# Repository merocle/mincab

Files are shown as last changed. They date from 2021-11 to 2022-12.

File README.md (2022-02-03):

# MinCab. Small carrier board for Raspberry Pi CM4

[Official website uplab.pro](https://uplab.pro/ls/)

[More information about MinCab project](https://uplab.pro/2021/10/mincab/)

[MinCab v2 real preview](https://twitter.com/Merocle/status/1486014687162552329) (fixed version in the repository)

Article on [tomshardware.com (link)](https://www.tomshardware.com/news/raspberry-pi-compute-module-4-mincab)

Article on [hackster.io (link)](https://www.hackster.io/news/ivan-kuleshov-s-mincab-is-the-smallest-functional-raspberry-pi-compute-module-4-carrier-board-yet-b1cacfa2abad)

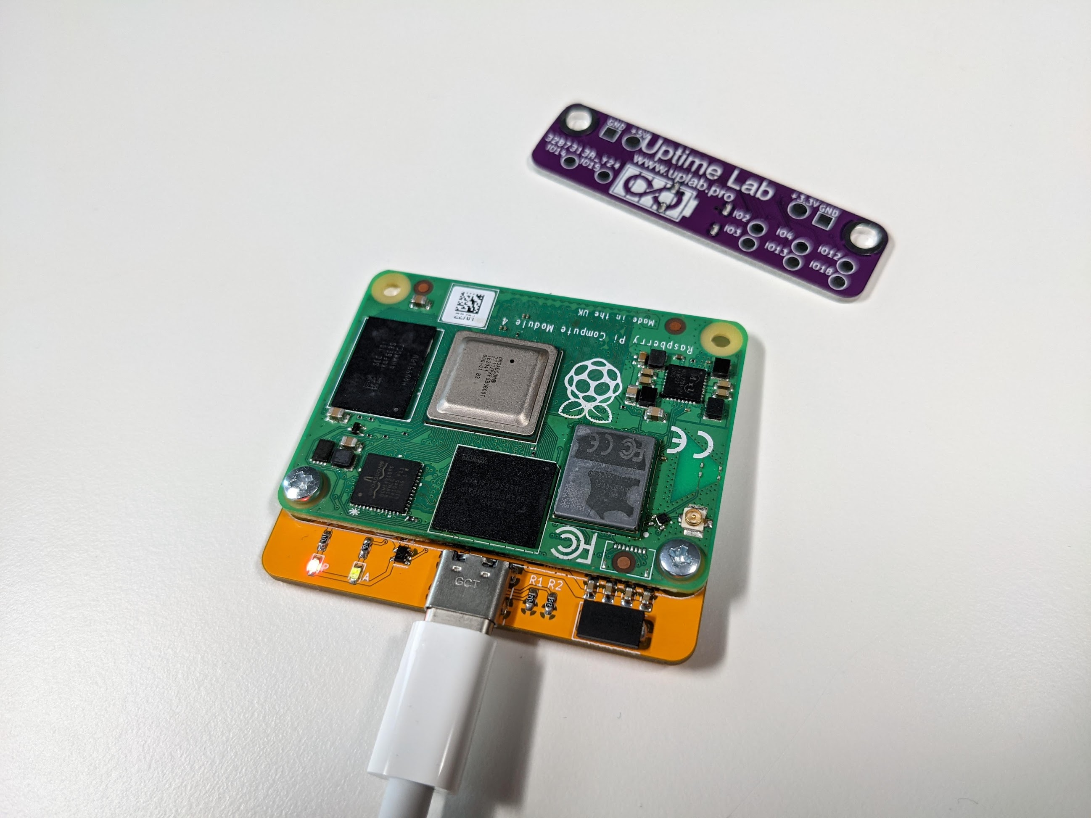
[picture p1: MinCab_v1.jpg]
Uptime MinCab carrier board for Raspberry Pi CM4

</br>
 <a rel="license" href="https://creativecommons.org/licenses/by-sa/4.0/">Creative Commons Attribution-ShareAlike 4.0 International License</a>.

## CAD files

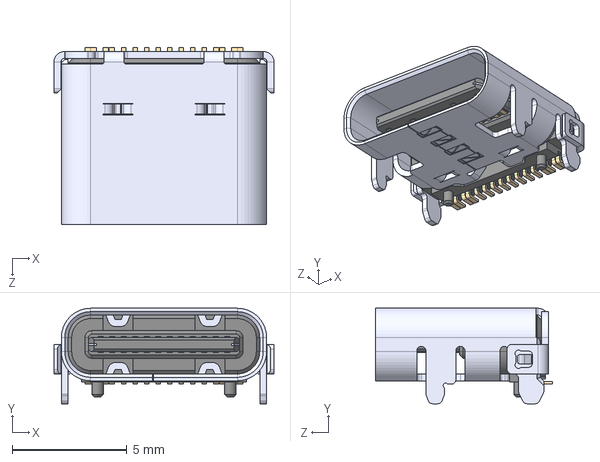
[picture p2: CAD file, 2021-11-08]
MinCab_v3.0/Kicad project/parts/USB4105-GF-A/USB4105-GF-A.step
9.58 x 4.16 x 7.71 mm

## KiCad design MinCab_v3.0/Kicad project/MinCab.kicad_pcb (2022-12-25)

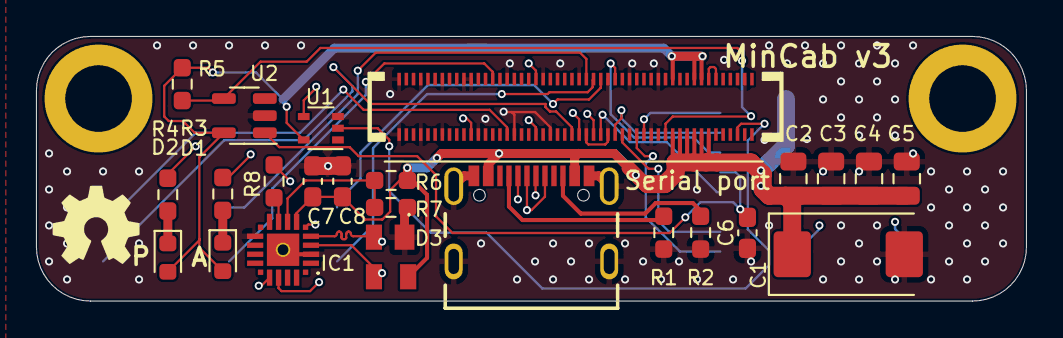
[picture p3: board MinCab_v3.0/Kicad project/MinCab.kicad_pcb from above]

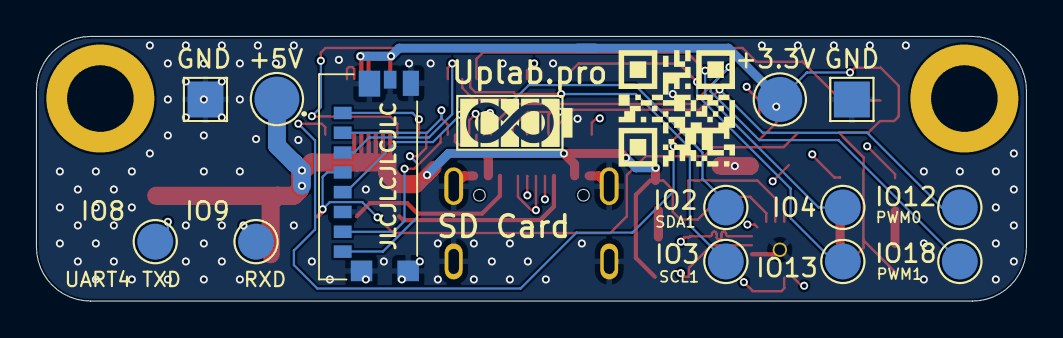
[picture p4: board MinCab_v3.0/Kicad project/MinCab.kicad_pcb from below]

Board: 4 copper layers, 55.0 x 14.7 mm, 37 parts (13 on the bottom side), 34 nets.

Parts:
+3.3V1: +3.3V; TestPoint_Pad_D2.5mm
+5V1: +5V; TestPoint_Pad_D2.5mm
C1: 100uF; CP_EIA-7343-31_Kemet-D
C2, C3, C4, C5: 10u; C_0805_2012Metric
C6: 10u; C_0603_1608Metric_Pad1.08x0.95mm_HandSolder
C7: 4.7uF; C_0603_1608Metric_Pad1.08x0.95mm_HandSolder
C8: 100nF; C_0603_1608Metric_Pad1.08x0.95mm_HandSolder
D1: LED Blue; LED_0603_1608Metric
D2: LED White; LED_0603_1608Metric
D3: SP0503BAHTG
GND1, GND2: GND; TestPoint_Pad_2.0x2.0mm
IC1: CP2102N-A02-GQFN20; CP2102NA02GQFN20
IO1: GPIO2; TestPoint_Pad_D2.0mm
IO2: GPIO12; TestPoint_Pad_D2.0mm
IO3: GPIO13; TestPoint_Pad_D2.0mm
IO4: GPIO3; TestPoint_Pad_D2.0mm
IO5: GPIO14; TestPoint_Pad_D2.0mm
IO6: GPIO4; TestPoint_Pad_D2.0mm
IO7: GPIO8; TestPoint_Pad_D2.0mm
IO8: GPIO9; TestPoint_Pad_D2.0mm
J1: USB4105-GF-A; GCT_USB4105-GF-A
J2: 47571-0001; 475710001
Module1: ComputeModule4; Raspberry-Pi-4-Compute-Module-big-holes
R1, R2: 5.1k; R_0603_1608Metric_Pad0.98x0.95mm_HandSolder
R3, R4: 1k; R_0603_1608Metric_Pad0.98x0.95mm_HandSolder
R5: 12K 1%; R_0603_1608Metric_Pad0.98x0.95mm_HandSolder
R6: 22K; R_0603_1608Metric_Pad0.98x0.95mm_HandSolder
R7: 47K; R_0603_1608Metric_Pad0.98x0.95mm_HandSolder
R8: 1K; R_0603_1608Metric_Pad0.98x0.95mm_HandSolder
U1: 74LVC1G07SE-7; SOT-353_SC-70-5
U2: RT9742GGJ5; SOT-23-5

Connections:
/+3.3v: +3.3V1.1, D1.2 (A), D2.2 (A), Module1.78 (GPIO_VREF(1.8v/3.3v_Input)), Module1.84 (+3.3v_(Output)), Module1.86 (+3.3v_(Output)), R5.1, U1.5 (VCC), U2.5 (IN)
/+5v: +5V1.1, C1.1, C2.1, C3.1, C4.1, C5.1, C7.2, C8.2, D3.4 (K_3), IC1.7 (VREGIN), J1.A4_B9 (VBUS), J1.B4_A9 (VBUS), Module1.77 (+5v_(Input)), Module1.79 (+5v_(Input)), Module1.81 (+5v_(Input)), Module1.83 (+5v_(Input)), Module1.85 (+5v_(Input)), Module1.87 (+5v_(Input)), R6.2
/D+: D3.3 (K_2), IC1.4 (D+), J1.A6 (DP1), J1.B6 (DP2)
/D-: D3.2 (K_1), IC1.5 (D-), J1.A7 (DN1), J1.B7 (DN2)
/GPIO2: IO1.1, Module1.58 (GPIO2)
/GPIO3: IO4.1, Module1.56 (GPIO3)
/GPIO4: IO6.1, Module1.54 (GPIO4)
/GPIO8: IO5.1, Module1.39 (GPIO8)
/GPIO9: IO7.1, Module1.40 (GPIO9)
/GPIO12: IO2.1, Module1.31 (GPIO12)
/GPIO13: IO3.1, Module1.28 (GPIO13)
/GPIO14: IC1.17 (RXD), Module1.55 (GPIO14)
/GPIO15: IC1.18 (TXD), Module1.51 (GPIO15)
/GPIO18: IO8.1, Module1.49 (GPIO18)
/SD_CLK: J2.P5 (CLK), Module1.57 (SD_CLK)
/SD_CMD: J2.P3 (CMD), Module1.62 (SD_CMD)
/SD_DAT0: J2.P7 (DAT0), Module1.63 (SD_DAT0)
/SD_DAT1: J2.P8 (DAT1), Module1.67 (SD_DAT1)
/SD_DAT2: J2.P1 (DAT2), Module1.69 (SD_DAT2)
/SD_DAT3: J2.P2 (CD/DAT3), Module1.61 (SD_DAT3)
/SD_PWR: C6.1, J2.P4 (VDD), U2.1 (OUT)
/SD_PWR_ON: Module1.75 (SD_PWR_ON), R5.2, U2.4 (EN)
/nPWR_LED: Module1.95 (nPI_LED_PWR), U1.2
GND: C1.2, C2.2, C3.2, C4.2, C5.2, C6.2, C7.1, C8.1, D3.1 (COMMON_A), GND1.1, GND2.1, IC1.3 (GND_1), IC1.12 (GND_2), IC1.21 (EP_GND), J1.A1_B12 (GND), J1.B1_A12 (GND), J1.S1 (SHELL_GND), J1.S2 (SHELL_GND), J1.S3 (SHELL_GND), J1.S4 (SHELL_GND), J2.G1 (GND_1), J2.G2 (GND_2), J2.G3 (GND_3), J2.G4 (POL), J2.G5 (DET), J2.P6 (VSS), Module1.1 (GND), Module1.2 (GND), Module1.7 (GND), Module1.8 (GND), Module1.13 (GND), Module1.14 (GND), Module1.20 (EEPROM_nWP), Module1.22 (GND), Module1.23 (GND), Module1.32 (GND), Module1.33 (GND), Module1.42 (GND), Module1.43 (GND), Module1.52 (GND), Module1.53 (GND), Module1.59 (GND), Module1.60 (GND), Module1.65 (GND), Module1.66 (GND), Module1.71 (GND), Module1.74 (GND), Module1.98 (GND), R1.2, R2.1, R7.1, U1.3 (GND), U2.2 (GND)
unnamed: D1.1 (K), R3.1
unnamed: D2.1 (K), R4.1
unnamed: IC1.6 (VDD), R8.1
unnamed: IC1.8 (VBUS), R6.1, R7.2
unnamed: IC1.9 (RSTB), R8.2
unnamed: J1.A5 (CC1), R1.1
unnamed: J1.B5 (CC2), R2.2
unnamed: Module1.21 (PI_nLED_Activity), R4.2
unnamed: Module1.88 (+1.8v_(Output)), Module1.90 (+1.8v_(Output))
unnamed: R3.2, U1.4

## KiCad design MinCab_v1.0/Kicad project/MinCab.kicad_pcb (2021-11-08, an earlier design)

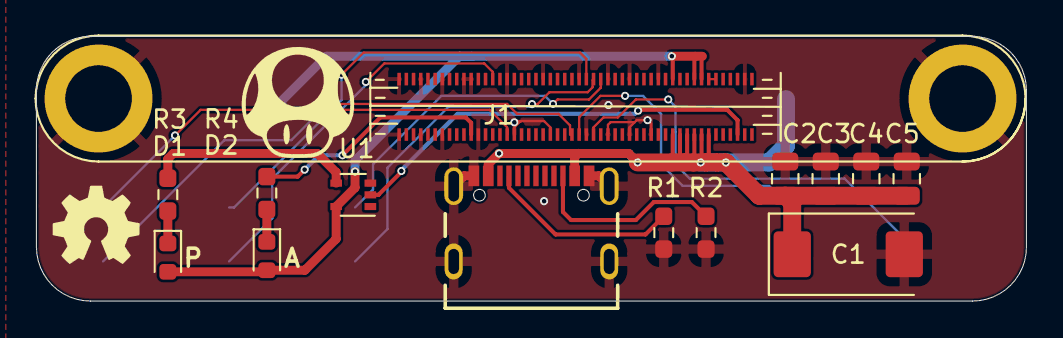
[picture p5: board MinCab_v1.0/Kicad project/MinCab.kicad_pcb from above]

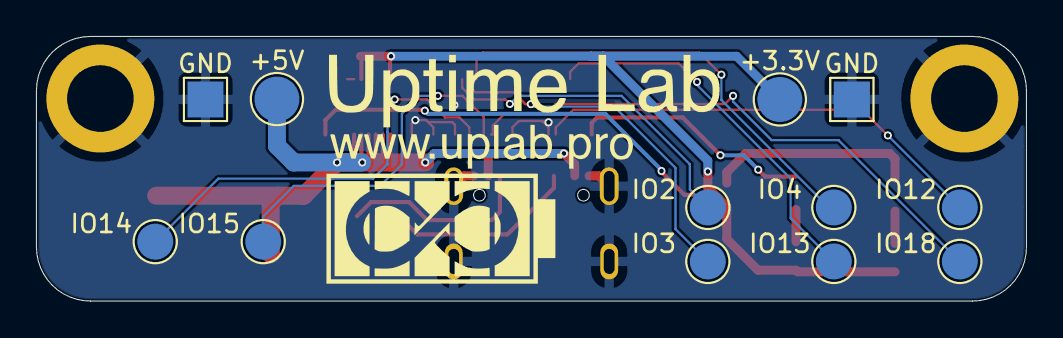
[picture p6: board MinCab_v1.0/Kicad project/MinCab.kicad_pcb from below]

Board: 2 copper layers, 55.0 x 14.7 mm, 26 parts (12 on the bottom side), 19 nets.

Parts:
+3.3V, +5V: TestPoint; TestPoint_Pad_D2.5mm
C1: 100uF; CP_EIA-7343-31_Kemet-D
C2, C3, C4, C5: 10u; C_0805_2012Metric
D1: LED Blue; LED_0603_1608Metric
D2: LED White; LED_0603_1608Metric
GND: TestPoint; TestPoint_Pad_2.0x2.0mm
GND#2: TestPoint; TestPoint_Pad_2.0x2.0mm
IO2, IO3, IO4, IO12, IO13, IO14, IO15, IO18: TestPoint; TestPoint_Pad_D2.0mm
J1: USB4105-GF-A; GCT_USB4105-GF-A
Module1: ComputeModule4; Raspberry-Pi-4-Compute-Module-big-holes
R1, R2: 5.1k; R_0603_1608Metric_Pad0.98x0.95mm_HandSolder
R3, R4: 1k; R_0603_1608Metric_Pad0.98x0.95mm_HandSolder
U1: 74LVC1G07SE-7; SOT-353_SC-70-5

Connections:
/+1.8v: Module1.88 (+1.8v_(Output)), Module1.90 (+1.8v_(Output))
/+3.3v: +3.3V.1, D1.2 (A), D2.2 (A), Module1.78 (GPIO_VREF(1.8v/3.3v_Input)), Module1.84 (+3.3v_(Output)), Module1.86 (+3.3v_(Output)), U1.5 (VCC)
/+5v: +5V.1, C1.1, C2.1, C3.1, C4.1, C5.1, J1.A4_B9 (VBUS), J1.B4_A9 (VBUS), Module1.77 (+5v_(Input)), Module1.79 (+5v_(Input)), Module1.81 (+5v_(Input)), Module1.83 (+5v_(Input)), Module1.85 (+5v_(Input)), Module1.87 (+5v_(Input))
/GPIO2: IO2.1, Module1.58 (GPIO2)
/GPIO3: IO3.1, Module1.56 (GPIO3)
/GPIO4: IO4.1, Module1.54 (GPIO4)
/GPIO12: IO12.1, Module1.31 (GPIO12)
/GPIO13: IO13.1, Module1.28 (GPIO13)
/GPIO14: IO14.1, Module1.55 (GPIO14)
/GPIO15: IO15.1, Module1.51 (GPIO15)
/GPIO18: IO18.1, Module1.49 (GPIO18)
/nPWR_LED: Module1.95 (nPI_LED_PWR), U1.2
GND: C1.2, C2.2, C3.2, C4.2, C5.2, GND.1, GND#2.1, J1.A1_B12 (GND), J1.B1_A12 (GND), J1.S1 (SHELL_GND), J1.S2 (SHELL_GND), J1.S3 (SHELL_GND), J1.S4 (SHELL_GND), Module1.1 (GND), Module1.2 (GND), Module1.7 (GND), Module1.8 (GND), Module1.13 (GND), Module1.14 (GND), Module1.20 (EEPROM_nWP), Module1.22 (GND), Module1.23 (GND), Module1.32 (GND), Module1.33 (GND), Module1.42 (GND), Module1.43 (GND), Module1.52 (GND), Module1.53 (GND), Module1.59 (GND), Module1.60 (GND), Module1.65 (GND), Module1.66 (GND), Module1.71 (GND), Module1.74 (GND), Module1.98 (GND), Module1.S2, R1.1, R2.2, U1.3 (GND)
unnamed: D1.1 (K), R3.1
unnamed: D2.1 (K), R4.1
unnamed: J1.A5 (CC1), R1.2
unnamed: J1.B5 (CC2), R2.1
unnamed: Module1.21 (PI_nLED_Activity), R4.2
unnamed: R3.2, U1.4

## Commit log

2021-11-08 Leeroy Jenkins
    no, just initial commit
    [MinCab-B_Cu.gbl, MinCab-B_Mask.gbs, MinCab-B_Paste.gbp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]
2021-12-01 added gerber files without mushroom
2022-02-03 MinCab v2 added
    Added MinCab v2 and changed the folder structure in the repository
    [MinCab-B_Cu.gbl, MinCab-B_Mask.gbs, MinCab-B_Paste.gbp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]
2022-12-25 MinCab 3.0 release
    Now the serial port is on board.
    For more information, visit https://uplab.pro/2021/10/mincab/
    [MinCab-B_Cu.gbl, MinCab-B_Mask.gbs, MinCab-B_Paste.gbp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]
